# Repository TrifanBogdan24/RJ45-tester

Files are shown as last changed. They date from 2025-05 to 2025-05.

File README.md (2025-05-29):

# RJ45 Tester

## Introducere

### De la idee la prototip

Vă amintiți primul laborator de **RL**?

Acolo am învățat cum să realizăm un **cablu UTP** pentru rețele Ethernet,
Procesul poarta numele de **sertizare**.
După realizarea cablului, acesta trebuie verificat ca functioneaza corect - adică dacă are continuitate.

Testarea se face folosind un dispozitiv dedicat.

De aici a pornit ideea proiectului meu: realizarea propriului meu [tester RJ45](https://www.optimusdigital.ro/ro/aparate-de-masura/4962-tester-rj45-rj11.html?search_query=rj45&results=22),
caruia i-am adus o serie de îmbunătățiri.

### Ce face dispozitivul?

Dispozitivul proiectat permite testarea cablurilor de rețea de tip **RJ45**,
oferind feedback vizual și auditiv privind corectitudinea conexiunilor dintre pini.

Prin simpla apăsare a unui buton, utilizatorul poate selecta tipul de cablu testat:
1. **Straight-through** - pentru conectarea dispozitivelor aflate pe *layere diferite* (ex: PC – switch)
2. **Crossover** - pentru conectarea dispozitivelor de *același layer* (ex: PC - PC)
3. **Rollover** (numit si *cablu de consola*) - pentru a conecta un dispozitiv la un echipament de retea si pentru a avea acces direct la CLI

După selectare, pe ecranul principal (128x160 SPI) este afișată o imagine cu ordinea corectă a firelor pentru tipul respectiv de cablu.

Rolul hardware-ului in testare:
- Se folosesc 2 socketi: unul dedicat pentru **sender**, iar celalalt pentru **receiver**
-  Fiecare soclu RJ-45 are 8 pini
- Fiecarui pin RJ-45 ii este asociat un LED de culoare verde care se va aprinde
    atunci cand semnalul transmis/primit pe pinul respectiv este de 1 logic.
- In momentul in care socket-ul de **receiver** receptioneaza **1 logic**, buzzer-ul va emite un beep scurt

Testarea efectiva presupune 2 verificari:
1. Se vor trimite semnale, secvential, iterand pinii **sender**-ului unul cate unul, cu mici pauze intre transmisii,
2. urmand un test final in care se vor activa simultan toti pinii **sender**-ului

Testar-ul poate fi oprită forțat, in orice moment,  prin apăsarea unui buton.

In timp ce display-ul pe SPI (de rezolutie mai mare)
afiseaza ordinea firelor in mufa RJ-45,
LCD-ul cu modul I2C va scrie pe ecran tipul de cablu **straight-through**/**crossover**
si indexul pinului de pe **sender** de pe care se trimit semnale
(e.g. *"Testing pin 1...8"*), sau mesajul *"Testing all pins"*.

### De ce este util?

Consider ca folosirea ecranelor face diferenta dintre un tester RJ-45 obisnuit
si device-ul.

Practic, este un instrument **"2 în 1"**: tester + ghid de conectare.

Sper ca dispozivitul pe care il proiectez
(imi propun sa ii fac si un **PCB compact**)
sa ajunga in mainile laborantilor de RL/CCNA1.
Acolo isi va atinge adevaratul potential.

## Descriere Generala

Schema bloc:

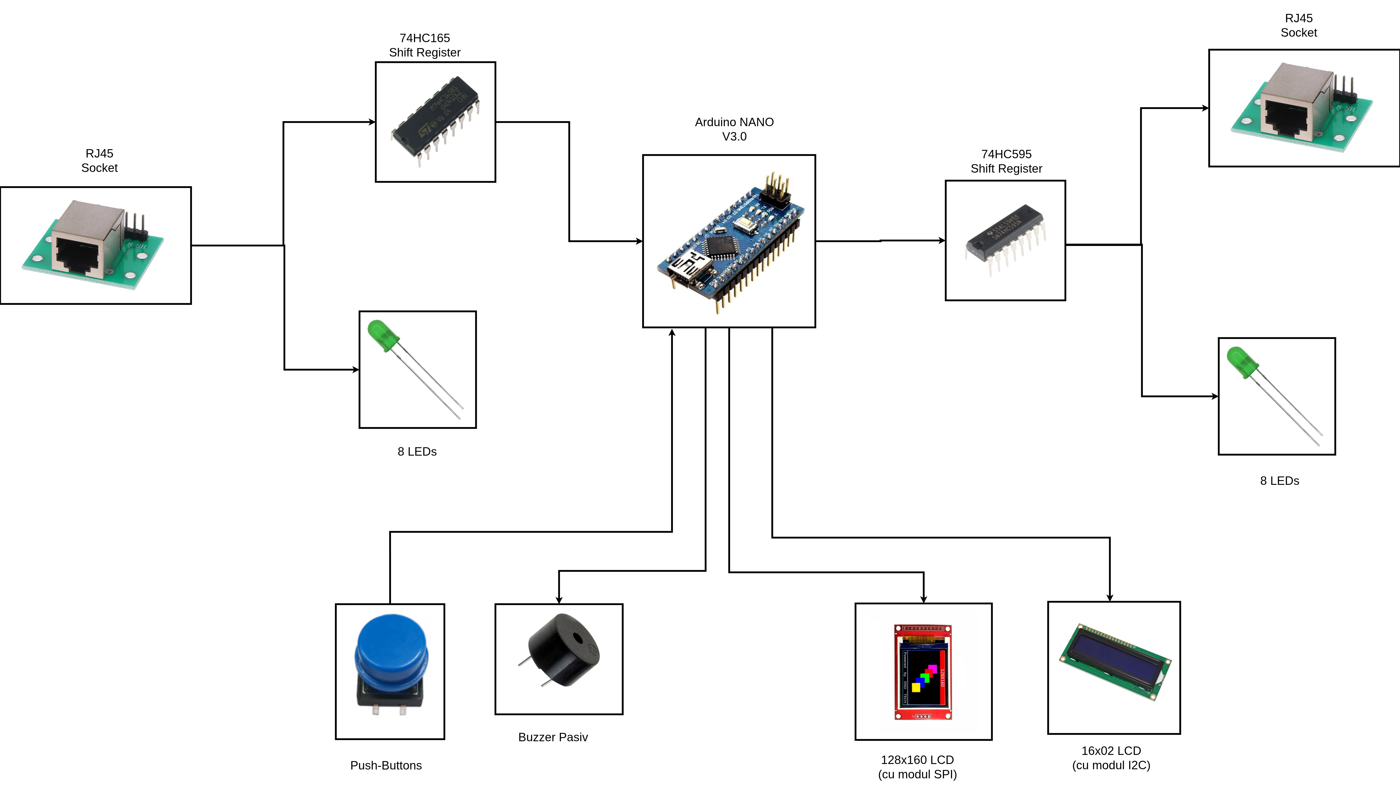
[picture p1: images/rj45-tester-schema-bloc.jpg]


## Hardware Design

### Lista Componente

| Componenta | Pret |
| :--- | :--- |
| [Arduino Nano V3.0](https://www.emag.ro/placa-de-dezvoltare-nano-v3-0-atmega328p-ch340-cu-cablu-usb-1414dr/pd/DTDC88YBM/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) | ~40 lei |
| 2x [RJ45 Adapter Board + Breakout Board + Pin Header](https://www.aliexpress.com/item/1005006421216570.html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) (de pe AliExpress 😊) | ~8 lei fiecare |
| 1x [74HC595 8-bit Shift Register](https://ardushop.ro/ro/circuite-integrate/1657-ic-shift-register-sn74hc595n-74hc595-6427854024978.html) (1 pin intrare, 8 pini de iesire) | 4 lei |
| 1x [74HC165 8-bit Shift Register](https://ardushop.ro/ro/electronica/683-74hc165-8-bit-shift-register-6427854008602.html) (1 pin iesire, 8 pini de intrare) | 8 lei |
| [LCD 16x02 cu interfata I2C](https://www.optimusdigital.ro/ro/optoelectronice-lcd-uri/2894-lcd-cu-interfata-i2c-si-backlight-albastru.html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) | ~16 lei |
| [Modul LCD SPI 160x128](https://ardushop.ro/ro/electronica/2124-modul-lcd-spi-128x160-6427854032546.html) | ~44 lei |
| 16x [LED Verde 3mm cu Lentile Difuze](https://www.optimusdigital.ro/ro/optoelectronice-led-uri/697-led-verde-de-3-mm-cu-lentile-difuze.html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) | 0,40 lei fiecare |
| 16x Rezistente 220 Ω (pt LED-uri) | |
| [Buzzer Pasiv](https://www.optimusdigital.ro/ro/audio-buzzere/12247-buzzer-pasiv-de-33v-sau-3v.html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) | 1 leu |
| 3x [Buton cu Capac Rotund](https://www.optimusdigital.ro/ro/butoane-i-comutatoare/1115-buton-cu-capac-rotund-alb.html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) | 2 lei fiecare |
| 3x Rezistente (de PULL-UP) de 10 kΩ (pt butoane) |
| 3x [Condensatoare ceramice de 47nF](https://www.optimusdigital.ro/ro/componente-electronice-condensatoare/7817-condensator-ceramic-47-nf-50-v.html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) (pt butoane) | 0,50 lei fiecare |
| 3x [Breadboard 830 puncte](https://ardushop.ro/ro/electronica/2297-breadboard-830-puncte-mb-102-6427854012265.html) | 20 lei fiecare |
| [Set fire Plusivo cu izolatie PVC (Fir unifilar) - 22 AWG](https://www.optimusdigital.ro/ro/kituri/12264-set-de-fire-cu-izolaie-pvc-22awg-6-culori-10m-fiecare-0721248989765.html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) | 45 lei |
| Jumpere tata-tata | |
| Jumpere mama-tata | |

> Set fire PVC:
>   - Size matters: cele de **22 AWG** se conecteaza cel mai bine in breadboard
>   - Calalalt tip de fire (silicon - multifilar): sunt bune de lipit, dar in niciun caz nu se pot infige intr-un breadboard

**Componente auxiliare**, specifice tester-ului RJ-45:
| Componenta | Pret |
| :--- | :--- |
| 2 metri cablue UTP | 0 lei (de la CCNA 😊)  |
| [Cleste Universal Sertizat Conectori RJ-45](https://www.emag.ro/cleste-universal-sertizat-conectori-rj-45-rj-12-rj-11-lhpnar0051/pd/DB3JFDBBM/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) | 15 lei |
| [SET 50 Buc - Mufa RJ45 UTP/FTP cu 8 pini 8P8C](https://www.emag.ro/set-50-buc-mufa-rj45-utp-ftp-cu-8-pini-8p8c-s50-rj45/pd/DZ94TCBBM/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) | 15 lei |
| [Tester Continuitate RJ45](https://www.optimusdigital.ro/ro/aparate-de-masura/4962-tester-rj45-rj11.html?search_query=rj45&results=22) | 15 lei |
| Baterie 9V | |

### Schema Electrica

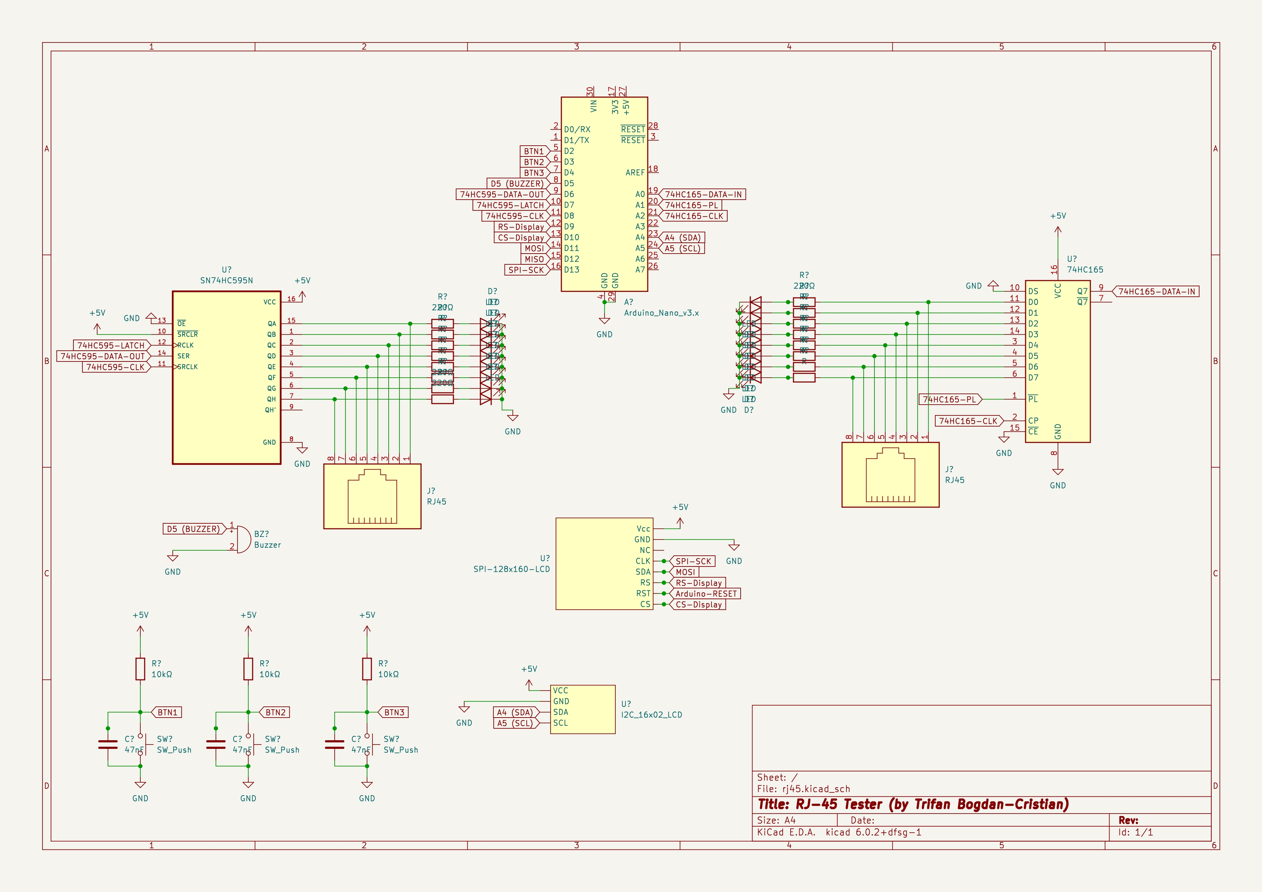
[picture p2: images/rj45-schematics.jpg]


### Pin configurations

#### Arduino

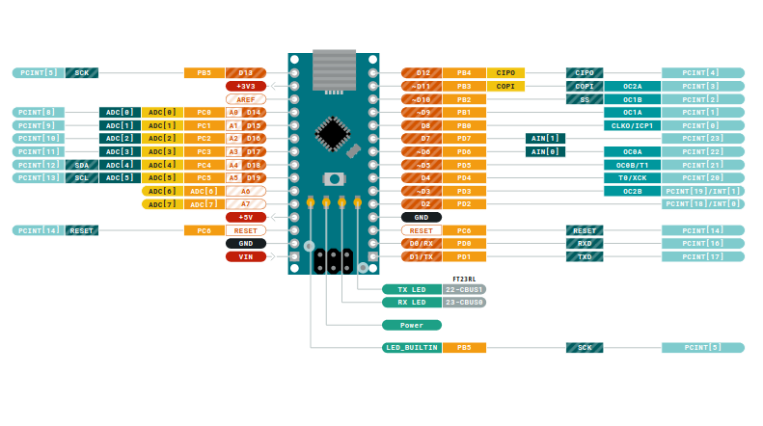
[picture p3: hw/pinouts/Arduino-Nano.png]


| Pin Arduino | Corespondent |
| :--- | :--- |
| D2 | Butonul albastru (BTN1) |
| D3 | Butonul rosu (BTN2) |
| D4 | Butonul alb (BTN3) |
| D5 | Buzzer pasiv |
| D6 | Data OUT 74HC595 (SER) |
| D7 | Latch 74HC595 (RCLK) |
| D8 | Clock 74HC595 (SRCLK) |
| D9 | RS-Display |
| D10 | CS-Diplsay |
| D11 | (SPI) MOSI |
| D12 | (SPI) MISO |
| D13 | (SPI) SCK|
| D14 (etichetat A0) | Data IN 74HC165 |
| D15 (etichetat A1) | PL 74HC165 |
| D16 (etichetat A2) | CLK 74HC165 |
| A4 | (I2C) SDA |
| A5 | (I2C) SCL |

#### 160x128 Display (pe SPI)

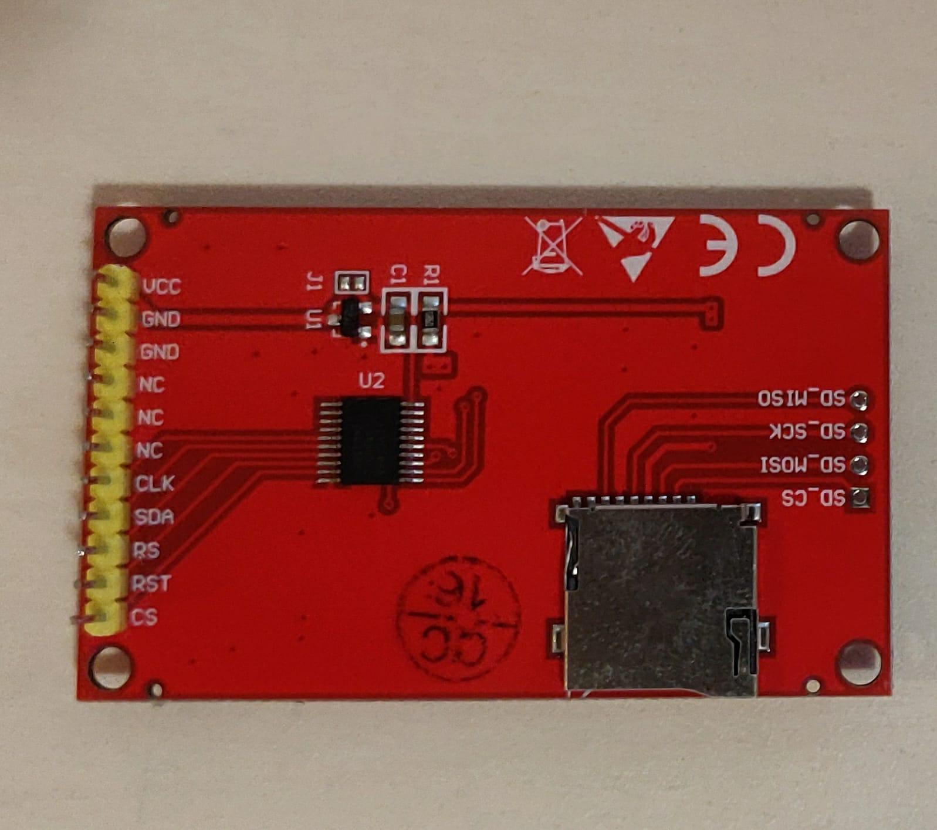
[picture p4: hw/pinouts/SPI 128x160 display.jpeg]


| Denumire pin | Descriere |
| :--- | :--- |
| Vcc | Vcc
| GND | Ground |
| NC | Not Connected (nu se conecteaza la nimic) |
| CLK | Clock |
| SDA | este pinul de **MOSI** (foarte confuz ca au scris SDA in loc de **MOSI**) |
| RS | Register Select |
| RST | Reset |
| CS | Chip Select |

> Pinul RS (Register Select) este cunoscut si sub numele de DC (Data Command).
> 
> Acest pin indica daca datele trimise pe SPI sunt:
> - comenzi (e.g.: seteaza pozitia cursorului)
> - date (e.g. afiseaza pixeli pe ecran)
> 
> Pinul are urmaoare functionalitate:
> - Daca RS/DC = 0 -> comanda
> - Daca RS/DC = 1 -> date

| Pin Display SPI | Corespondent |
| :--- | :--- |
| Vcc | 5V |
| GND | GND |
| NC | nu se conecteaza la nimic |
| CLK | Arduino D13 (SPI SCK) |
| SDA | Arduino D11 (SPI MOSI) |
| RS | Arduino D9 |
| RST | Arduino RESET |
| CS | Arduino D10 |

#### 74HC595 shift register

> Shift register-ul **74HC595** are o singura intrare si **8 iesiri paralele**.

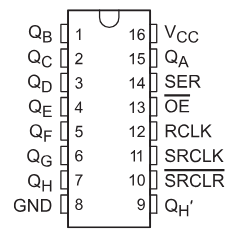
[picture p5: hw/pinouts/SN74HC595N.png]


| Index pin 74HC595 | Denumire pin 74HC595 | Corespondent |
| :--- | :--- | :--- |
| 15 | Q<sub>A</sub> | LED 1 (cel mai de sus) & pin 1 socket RJ-45 sender |
| 1  | Q<sub>B</sub> | LED 2 (al doilea cel mai de sus) & pin 2 socket RJ-45 sender |
| 2  | Q<sub>C</sub> | LED 3 & pin 3 socket RJ-45 sender |
| 3  | Q<sub>D</sub> | LED 4 & pin 4 socket RJ-45 sender |
| 4  | Q<sub>E</sub> | LED 5 & pin 5 socket RJ-45 sender |
| 5  | Q<sub>F</sub> | LED 6 & pin 6 socket RJ-45 sender |
| 6  | Q<sub>G</sub> | LED 7 & pin 7 socket RJ-45 sender |
| 7  | Q<sub>H</sub> | LED 8 & pin 8 socket RJ-45 sender |
| 8  | GND | GND |
| 9  | !Q<sub>H</sub> | nmk |
| 10 | !SRCLR | 5V |
| 11 | SRCLK | Arduino D8 |
| 12 | RCLK | Arduino D7 |
| 13 | !OE | GND |
| 14 | SER | Arduino D6 |
| 16 | Vcc | 5V |

> LED-ul la care fac referire aici sunt cele din **partea stanga**, asociate **sender**-ului.

#### 74HC165 shift register

> Shift register-ul **74HC165** are o singura iesire si **8 intrari paralele**.

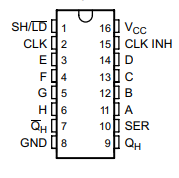
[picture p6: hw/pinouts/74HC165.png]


| Index pin 74HC165 | Denumire pin 74HC165 | Corespondent |
| :--- | :--- | :--- |
| 7 | !Q<sub>H</sub> | nmk |
| 9 | Q<sub>H</sub> | Arduino D14 (etichetat A0) |
| 1 | SH/!LD | Arduino D15 (etichetat A1) |
| 2 | CLK | Arduino D16 (etichetat A2) |
| 8 | GND | GND |
| 16 | Vcc | 5V |
| 10 | SER | GND |
| 15 | CLK INH | GND |
| 11 | A (out1) | LED 1 (cel mai de sus) & pin 1 socket RJ-45 receiver |
| 12 | B (out1) | LED 2 (al doilea cel mai de sus) & pin 2 socket RJ-45 receiver |
| 13 | C (out1) | LED 3 & pin 2 socket RJ-45 receiver |
| 14 | D (out1) | LED 4 & pin 3 socket RJ-45 receiver |
| 3 | E (out1) | LED 5 & pin 4 socket RJ-45 receiver |
| 4 | F (out1) | LED 6 & pin 5 socket RJ-45 receiver |
| 5 | G (out1) | LED 7 & pin 6 socket RJ-45 receiver |
| 6 | H (out1) | LED 8 & pin 7 socket RJ-45 receiver |

> LED-ul la care fac referire aici sunt cele din **partea dreapta**, asociate **receiver**-ului.

### Debounce butoane: Filtru trece-jos

Pentru a trata **debounce-ul butoanelor** exclusiv din hardware,
m-am gandit sa introduc in circuit un **filtru trece-jos**,
punand cate un condensator ceramic in paralel cu fiecare buton.

Constanta de timp τ:

```
τ = R*C =10kΩ*47nF = 10^4 + 47*10^(-9) = 47*10^(-5) = 470us

5*τ=5*470μs≈2.35ms
```

Astfel, schimbarile mai rapide de **2.35 ms** ale butoanelor
vor fi ignorate (la nivel hardware) de aceste filtre.

> Chiar si asa, eu tot am lasat in cod un mic **delay**
> (unul mult mai mare decat ce poate circuitul construit de mine sa filtreze).

### Progresul fizic, pe etape

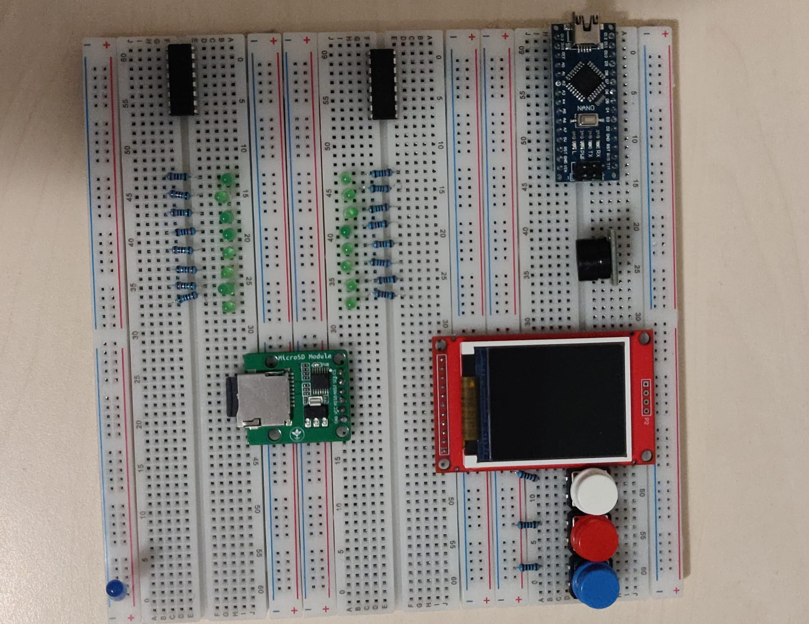
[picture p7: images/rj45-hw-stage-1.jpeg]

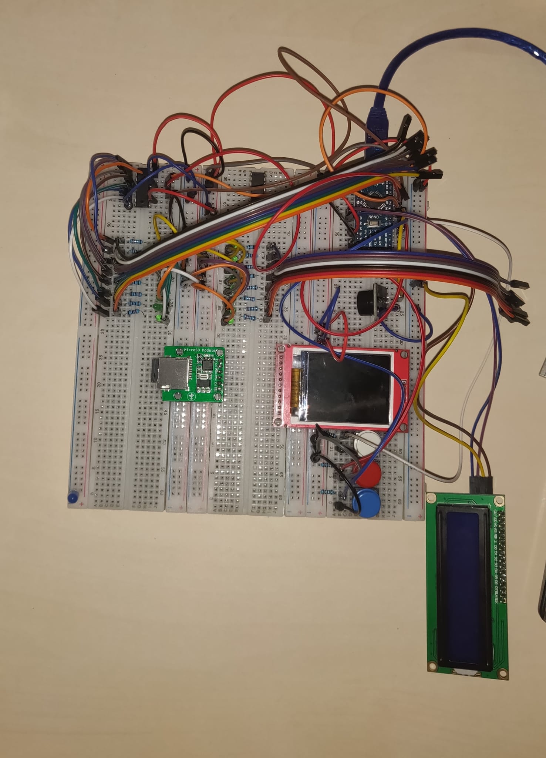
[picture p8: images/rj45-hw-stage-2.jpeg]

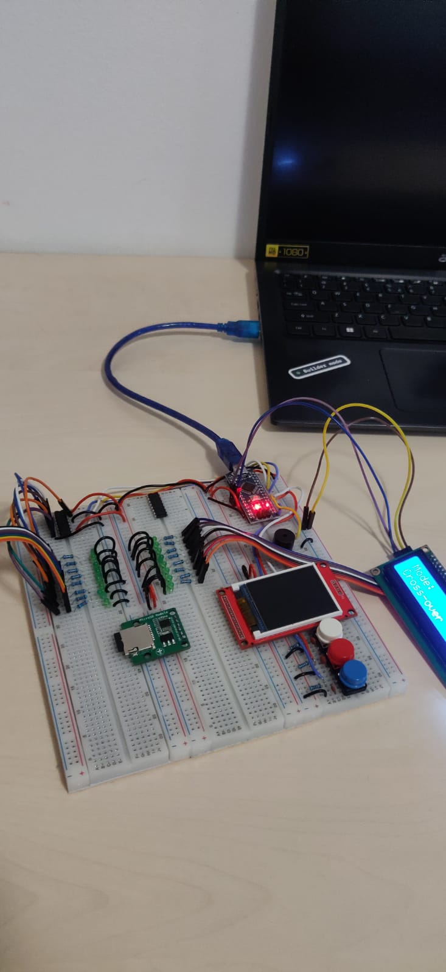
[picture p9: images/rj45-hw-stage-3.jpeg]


## Software Design

Biblioteci folosite:
- **Arduino.h**: biblioteca default pentru placa de dezvoltare
- **LiquidCrystal_I2C.h**: imi permite scrierea caracterelor pe ecranul secundar (cel pe I2C, de rezolutie 16x02)
- **Adafruit_GFX.h**, **Adafruit_ST7735.h**: pentru interactiunea cu display-ul principal (cel pe SPI, de rezolutie 160x128)

Repo GitHub: <https://github.com/TrifanBogdan24/RJ45-tester> - codul sursa se gaseste in folderul **src/**.

Am asociat fiecarui buton cate o intrerupere:
- Butonul **albastru** - intreruperea **INT0** - schimba tipul de cablare (crossover/straigh-through)
- Butonul **rosu** - intreruperea **INT1** - opreste fortat rularea testului
- Butonul **alb** - intreruperea **PCINT20** (din **PCINT2_vect**)  - porneste algoritmul de testare:

Descrierile functiilor:
- `ISR(INT0_vect)`:
  - rutina de tratare a intreruperii, generata la apasarea butonului **albastru** (schimba tipul de cablare)
  - Marcheaza flag-ul `volatile bool pressedBTN1`
- `ISR(INT1_vect)`: 
  - rutina de tratare a intreruperii, generata la apasarea butonului **rosu** (oprirea fortata a algoritmului de testare)
  - Marcheaza flag-ul `volatile bool pressedBTN2`
- `ISR(PCINT2_vect)`:
  - rutina de tratare a intreruperii, generata la apasarea butonului **alb** (pornirea algoritmului de testare)
  - Marcheaza flag-ul `volatile bool pressedBTN3`
- `void beep_okay()`: controleaza buzzer-ul sa emita bazait scurt, in semn ca totul este in regula
- `void beep_not_okay()`: controleaza buzzer-ul sa emita un semnal sonor de eroare
- `void cable_type_first_line_lcd()`: scrie tipul de cablare pe prima linia a LCD-ului de rezolutie 16x02
- `void cable_mode_full_lcd()`:
  scrie pe textul "Mode:" pe prima linia a display-ului secundar (cel pe I2C, de 16x02),
  iar pe a doua, tipul de cablare
- `void force_stop_handler()`:
  - Functia este apelata in urma apasarii butonului **rosu**.
  Opreste fortat algoritmul de testare,
  dar nu inainte de a afisa pe ecranul LCD pe I2C un mesaj sugestiv in acest sens
  `lcd.print("Force stop!");`
- `void write_to_sender_socket()`:
  - Variabila `bool pinsSenderSocket[8]` retine starea pinilor din mufa RJ-45 de transmisie
  - Functia scrie valorile din `bool pinsSenderSocket[8]` in shift register-ul **74HC595**,
  - Scrierea (chiar si pe un singur pin) al socket-ului sender presupune scrierea tuturor celor 8 valori
    catre **shift register**, in ordine inversa
    (intrucat acesta foloseste **MSB**: prima valoare primita va fi asociata ultimului pin)
- `void init_sender_pins()`:
  Este apelata la pornirea micro-controler-ului
  pentru a trata starea initiala indefinita
  (uneori LED-uri se pot aprinde aleator, fara ca eu nici macar sa fi scris ceva in shift register)
  a shift register-ului **74HC595**, asociat socket-ului sender.
- `void fetch_receiver_socket()`:
  Citeste valorile de pe shift register-ul **74HC165** (asociat socket-ului receiver)
  si le scrie in variabila `bool pinsReceiverSocket[8];`
- `bool is_correct_wiring(int pin_index)`:
  - Apeleaza `is_correct_wiring` pentru a citi semnalele de pinii socket-ului receiver
  - Si verifica daca valorile corespund unei cablari corecte,
  in raport cu indexul pinului activat pe mufa RJ-45 de transmisie
- `int test_individual_rj45_pins()`:
  - Algoritmul propriu zis de testare
  - Parcurge iterativ, de la 1 la 8, toti pinii socket-ului sender si
    1. Scrie pe ecranul secundar (16x02): modul de cablare, indexul pinului RJ-45 de transmisie
      si indexul corect pe care se asteapta sa primeasca semnal de pe pinul RJ-45 de receptie
    2. Scrie "1 logic" in iesirea (shift register-ului) **74HC595** corespunzatoare pinului ales:
      lucru care va produce aprinderea unui LED
    3. Ruleaza un mic `delay()` pentru a ma asigura ca semnalul are timp sa ajunga de la un capat la altul
    4. Apeleaza functia `is_correct_wiring` pentru a afla daca semnalul ajuns unde trebuie:
      - Daca da, va scrie in *"OK"* in coltul dreapta-jos al display-ului secundar si va emita un bapait scurt
      - Altfe, va scrie *"NOK"* pe LCD si va produce un sunet de avertistment
  - Functia verifica constant daca butonul **rosu** a fost apasat (flag-ul `pressedBTN2` a fost setat),
    caz in care opreste fortat algorimul de testare, apeland `force_stop_handler()` in cod
- `void init_tft_lcd()`: initializeaza display-ul principal (cel pe SPI, de rezolutie 160x128)
- `void draw_straight_through_wiring()`/`void draw_crossover_wiring()`/`void draw_rollover_wiring()`:
  - Aceste functii afiseaza grafic ordinea firelor pentru cele doua capete ale unui cablu de retea
  - In functie de tipul de cablare selectat (straight-through/crossover/rollover)
  - Ordinea firelor este redata conform standardelor prezentate in **cursul de RL**
- `setup()`
  - configureza pinii de Input/Outpt
  - activeaza intreruperile
  - initiaza display-urile
  - scrie in registrii
- `loop()`
  - Verifica si trateaza flag-urile `pressedBTN1` si `pressedBTN3`
  - > NOTA: flag-ul `pressedBTN2` este tratat in interiorul algoritmului de testare (in functia `test_individual_rj45_pins()`)
  - Reseteaza flag-urile
  - Ruleaza `delay()`

```c
tft.fillRect(x_upper_left_corner, y_upper_left_corner, width, height, ST77XX_<color>);
```

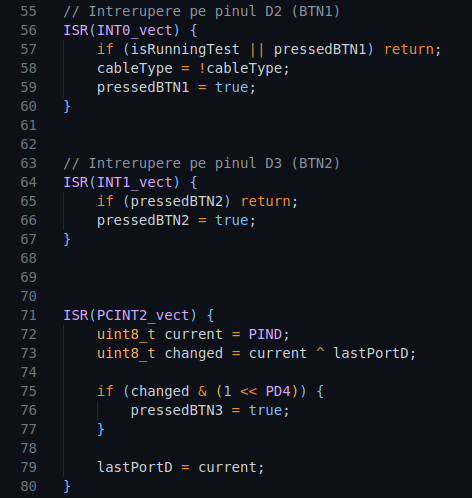
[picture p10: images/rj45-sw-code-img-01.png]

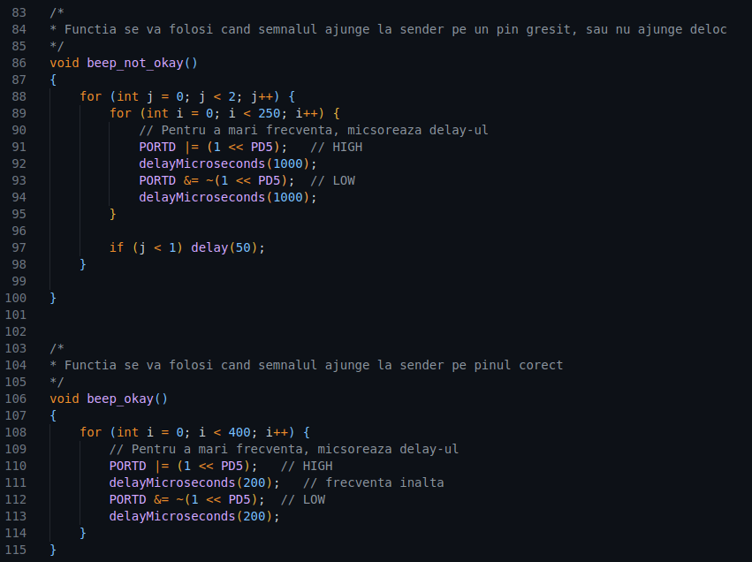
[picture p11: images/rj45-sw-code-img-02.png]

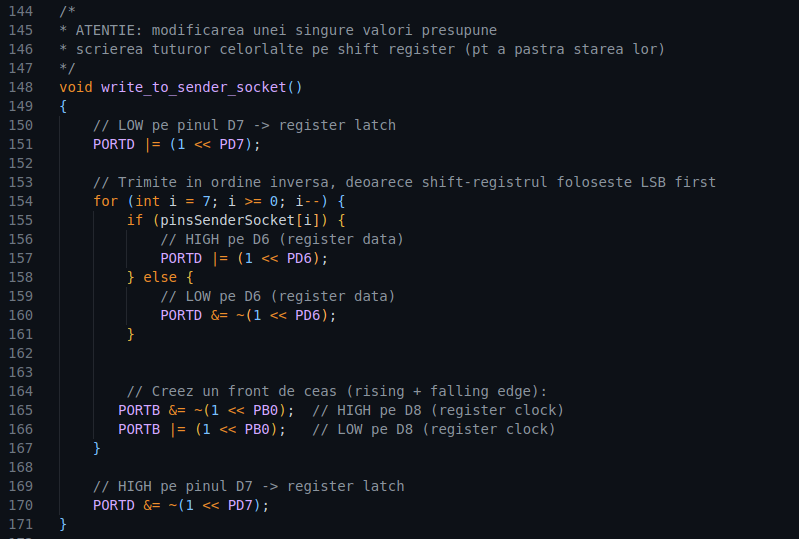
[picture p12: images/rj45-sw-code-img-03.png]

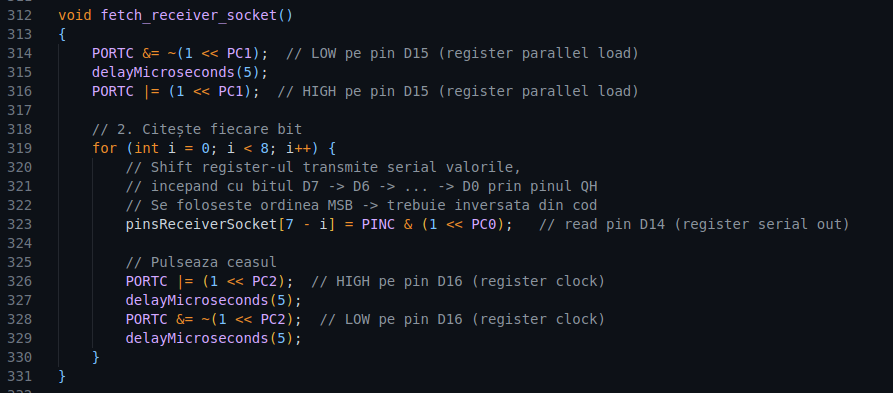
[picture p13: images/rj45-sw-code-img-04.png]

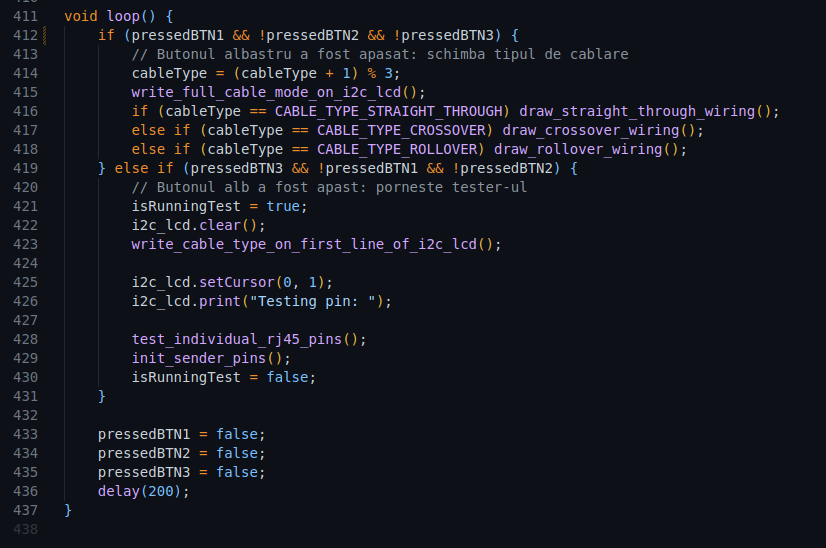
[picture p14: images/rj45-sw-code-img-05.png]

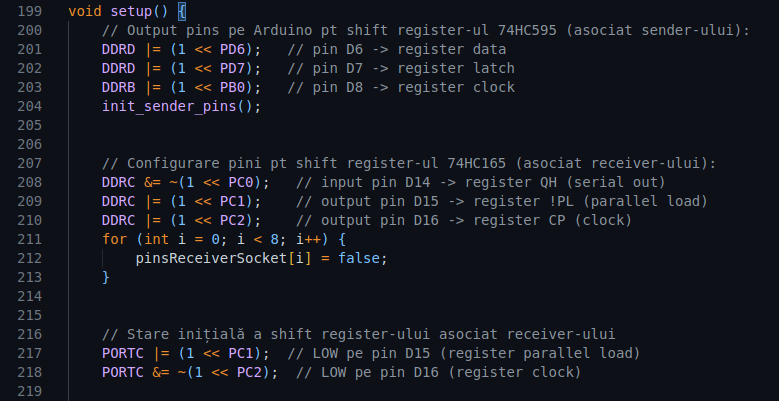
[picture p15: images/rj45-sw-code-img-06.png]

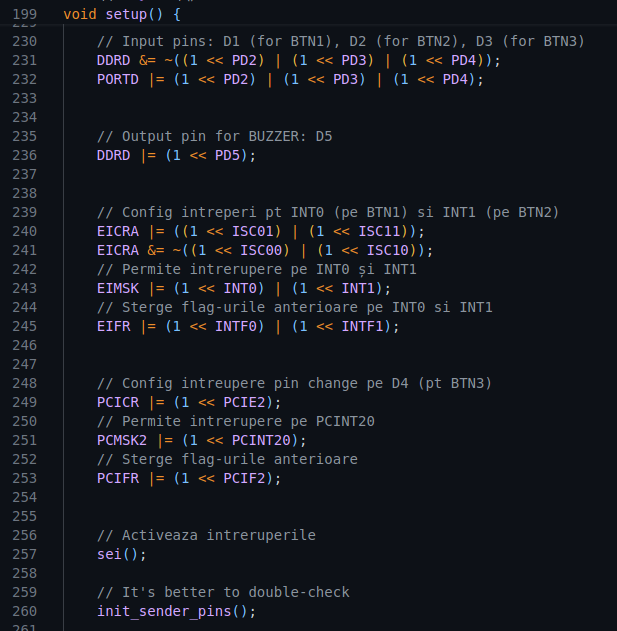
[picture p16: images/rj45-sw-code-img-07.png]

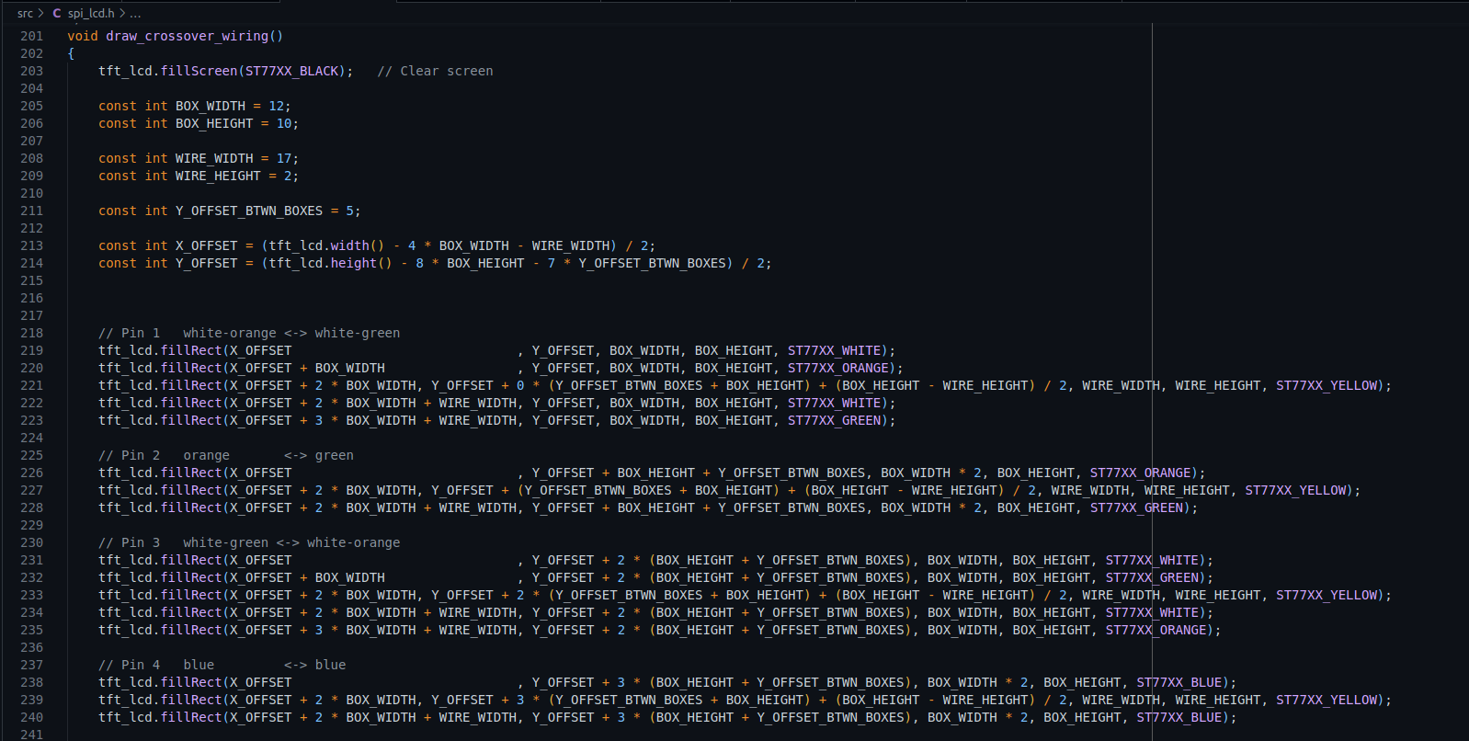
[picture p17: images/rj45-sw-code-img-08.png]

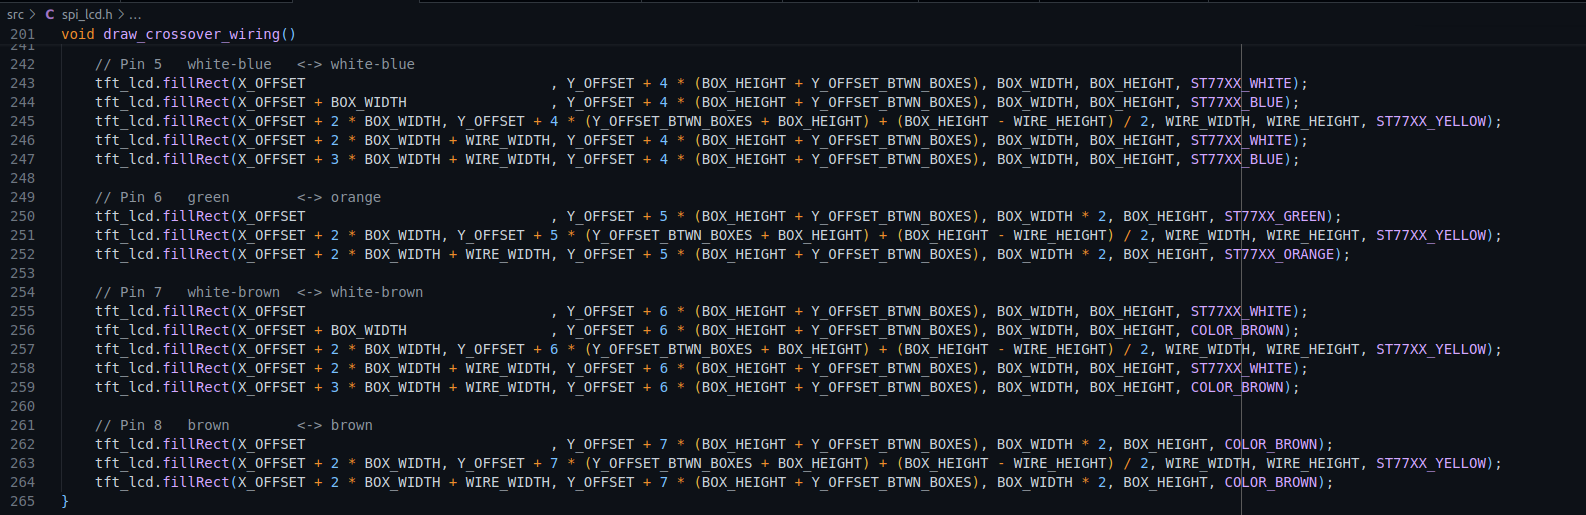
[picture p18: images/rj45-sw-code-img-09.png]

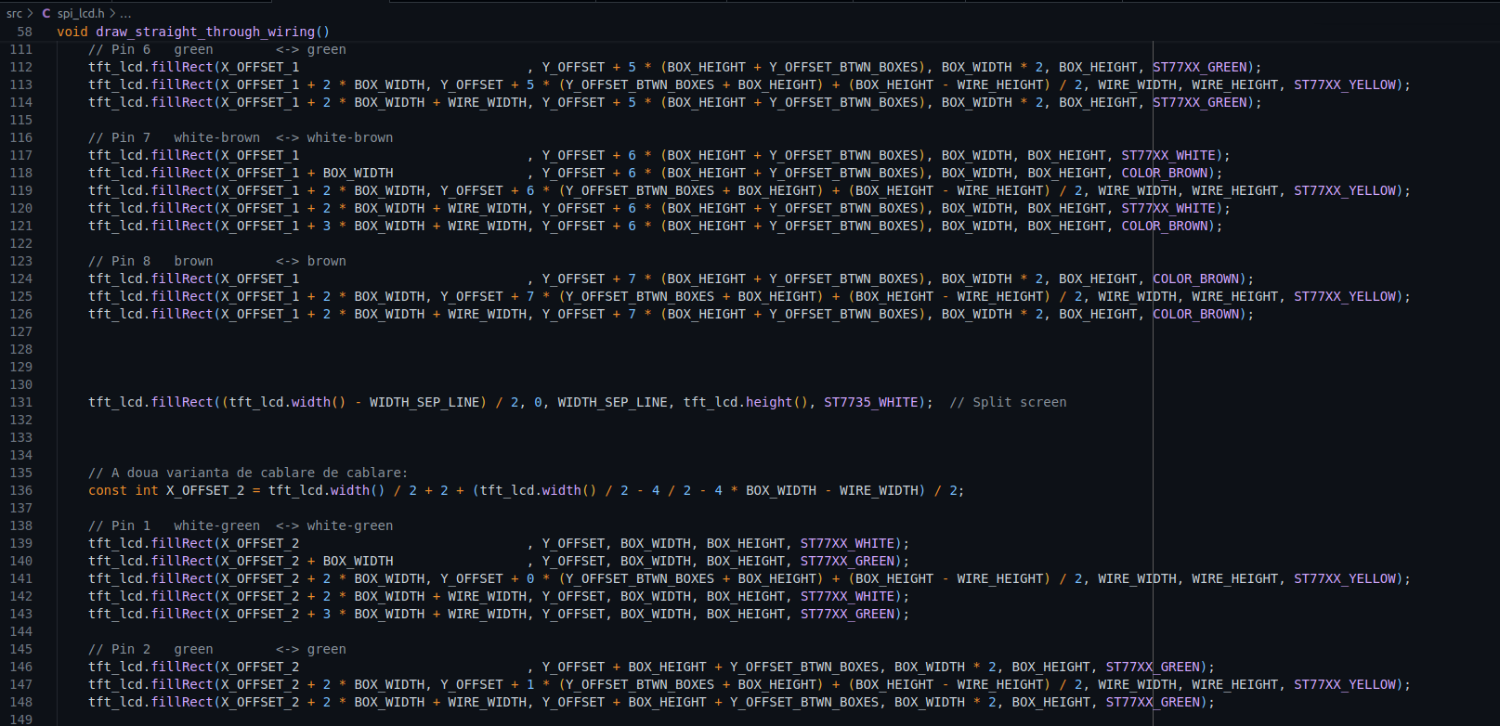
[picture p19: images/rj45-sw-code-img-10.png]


Repo GitHub: <https://github.com/TrifanBogdan24/RJ45-tester>

YouTube: <https://www.youtube.com/shorts/1yIg8dGbAU8>

## Concluzii

- Dat fiind faptul ca nu am avut succes la afisarea pe ecranul 160x128 a unor imagini **.bmp** luate de pe un card microSD,
  a trebuit sa renunt complet la modulul microSD
- In alta ordine de idei, pentru a desena modul de cablare, am mers pe o idee mai programatica,
  **EGC**-style: m-am apucat si am desenat eu dreptunghiuri pe ecran, colorandu-ule corespunzator.
  Rezultatul final cred ca este mult mai bun decat daca as fi transformat niste screen-shoot-uri la imagini **.bmp** de rezolutie joasa
- Cateva probleme pe care le-am intampinat in timpul acestui proiect au fost create de **shift register**-ul **74HC595** (cel cu 8 iesiri paralele):
  - Are o stare initiala random (am rezolvat scriind 0 logic pe toate iesirile)
  - Exista un **delay** (am observat ca este undeva la **200-300 ms**) din momentul in care dau o valoare inspre shift register si momentul in care semnalul iese corect din acesta 

## Resurse folosite

Pt cablurile pe care le folosesc pe breadboard: <https://www.youtube.com/shorts/3qbz26m9SPA>

[#13 How To Create Custom Symbols in KiCad 7.0 With KLC](https://www.youtube.com/watch?v=baCGoK8MuH0)

Data-sheets:
- [Arduino NANO pinout](https://docs.arduino.cc/resources/pinouts/A000005-full-pinout.pdf)

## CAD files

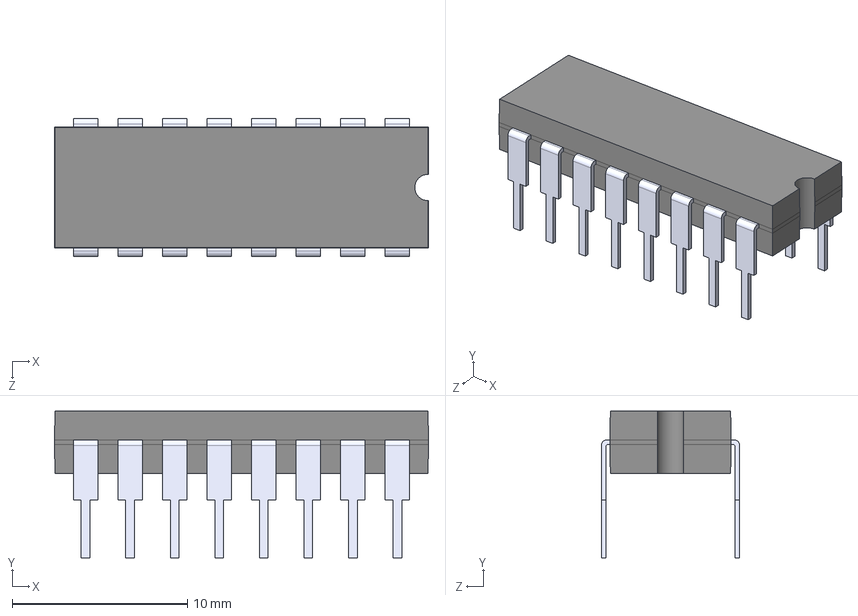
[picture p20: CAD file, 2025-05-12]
hw/rj45-kicad/SN74HC595N/SN74HC595N.step
21.3 x 8.38 x 7.90 mm

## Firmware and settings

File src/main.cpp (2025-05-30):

#include <Arduino.h>
#include <LiquidCrystal_I2C.h>
#include "spi_lcd.h"


#define CABLE_TYPE_STRAIGHT_THROUGH (int) 0
#define CABLE_TYPE_CROSSOVER        (int) 1
#define CABLE_TYPE_ROLLOVER         (int) 2



// Pini rezervati pe Arduino pt display-ul pe SPI (128x160):
#define PIN_IMAGE_DIPSLAY_CS (int) 10  // Chip Select -> D10
#define PIN_IMAGE_DISPLAY_RS (int) 14  // Register Select -> A0 (D14)




LiquidCrystal_I2C i2c_lcd(0x27, 16, 2);


// 0 = Straight-through ; 1 = Crossover ; 2 = Rollover
int cableType = CABLE_TYPE_STRAIGHT_THROUGH;
int imageTypeOnDisplay = 0;

volatile bool pressedBTN1 = false;   // Blue button (switch cable type)
volatile bool pressedBTN2 = false;   // Red button (force stop)
volatile bool pressedBTN3 = false;   // White button (start tester)

bool isRunningTest = false;

// Pentru intreruperile pe PCINT
volatile uint8_t lastPortD = 0;


const int dataPin = A1;  // QH (serial out)
const int plPin   = A2;  // /PL (parallel load)
const int clkPin  = A3;  // CP (clock)

// Vector de stocare a bitilor
bool pinsReceiverSocket[8];
bool pinsSenderSocket[8];



// Intrerupere pe pinul D2 (BTN1)
ISR(INT0_vect) {
    if (isRunningTest) return;
    pressedBTN1 = true;
}


// Intrerupere pe pinul D3 (BTN2)
ISR(INT1_vect) {
    pressedBTN2 = true;
}



ISR(PCINT2_vect) {
    if (isRunningTest) return;

    uint8_t current = PIND;
    uint8_t changed = current ^ lastPortD;

    if (changed & (1 << PD4)) {
        pressedBTN3 = true;
    }

    lastPortD = current;
}


/*
* Functia se va folosi cand semnalul ajunge la sender pe un pin gresit, sau nu ajunge deloc
*/
void beep_not_okay()
{
    for (int j = 0; j < 2; j++) {
        for (int i = 0; i < 250; i++) {
            // Pentru a mari frecventa, micsoreaza delay-ul
            PORTD |= (1 << PD5);   // HIGH
            delayMicroseconds(1000);
            PORTD &= ~(1 << PD5);  // LOW
            delayMicroseconds(1000);
        }

        if (j < 1) delay(50);
    }

}


/*
* Functia se va folosi cand semnalul ajunge la sender pe pinul corect
*/
void beep_okay()
{
    for (int i = 0; i < 400; i++) {
        // Pentru a mari frecventa, micsoreaza delay-ul
        PORTD |= (1 << PD5);   // HIGH
        delayMicroseconds(200);   // frecventa inalta
        PORTD &= ~(1 << PD5);  // LOW
        delayMicroseconds(200);
    }
}

void write_cable_type_on_first_line_of_i2c_lcd()
{
    i2c_lcd.setCursor(0, 0);
    if (cableType == CABLE_TYPE_STRAIGHT_THROUGH) {
        i2c_lcd.print("Straight-through");
    } else if (cableType == CABLE_TYPE_CROSSOVER) {
        i2c_lcd.print("Crossover      ");
    } else if (cableType == CABLE_TYPE_ROLLOVER) {
        i2c_lcd.print("Rollover        ");
    }
}


void write_full_cable_mode_on_i2c_lcd()
{
    i2c_lcd.clear();
    i2c_lcd.setCursor(0, 0);
    i2c_lcd.print("Mode:");
    i2c_lcd.setCursor(0, 1);

    if (cableType == CABLE_TYPE_STRAIGHT_THROUGH) {
        i2c_lcd.print("Straight-through");
    } else if (cableType == CABLE_TYPE_CROSSOVER) {
        i2c_lcd.print("Crossover      ");
    } else if (cableType == CABLE_TYPE_ROLLOVER) {
        i2c_lcd.print("Rollover        ");
    }
}



/*
* ATENTIE: modificarea unei singure valori presupune
* scrierea tuturor celorlalte pe shift register (pt a pastra starea lor)
*/
void write_to_sender_socket()
{
    // HIGH pe pinul D7 -> register latch
    PORTD |= (1 << PD7);
  
    // Trimite in ordine inversa, deoarece shift-registrul foloseste LSB first
    for (int i = 7; i >= 0; i--) {
        if (pinsSenderSocket[i]) {
            // HIGH pe D6 (register data)
            PORTD |= (1 << PD6);
        } else {
            // LOW pe D6 (register data)
            PORTD &= ~(1 << PD6);
        }
  

        // Creez un front de ceas (rising + falling edge):
       PORTB &= ~(1 << PB0);  // LOW pe D8 (register clock)
       PORTB |= (1 << PB0);   // HIGH pe D8 (register clock)
    }
  
    // LOW pe pinul D7 -> register latch
    PORTD &= ~(1 << PD7);
}


void init_sender_pins()
{
    for (int i = 0; i < 8; i++) {
        pinsSenderSocket[i] = false;
    }
    write_to_sender_socket();
}





void setup() {
    // Output pins pe Arduino pt shift register-ul 74HC595 (asociat sender-ului):
    DDRD |= (1 << PD6);   // pin D6 -> register data
    DDRD |= (1 << PD7);   // pin D7 -> register latch
    DDRB |= (1 << PB0);   // pin D8 -> register clock
    init_sender_pins();


    // Configurare pini pt shift register-ul 74HC165 (asociat receiver-ului):
    DDRC &= ~(1 << PC0);   // input pin D14 -> register QH (serial out)
    DDRC |= (1 << PC1);    // output pin D15 -> register !PL (parallel load)
    DDRC |= (1 << PC2);    // output pin D16 -> register CP (clock) 
    for (int i = 0; i < 8; i++) {
        pinsReceiverSocket[i] = false;
    }


    // Stare inițială a shift register-ului asociat receiver-ului
    PORTC |= (1 << PC1);  // LOW pe pin D15 (register parallel load)
    PORTC &= ~(1 << PC2);  // LOW pe pin D16 (register clock)


    cableType = CABLE_TYPE_STRAIGHT_THROUGH;
    imageTypeOnDisplay = 0;

    i2c_lcd.begin(16, 2);
    i2c_lcd.backlight();

    write_full_cable_mode_on_i2c_lcd();


    // Input pins: D1 (for BTN1), D2 (for BTN2), D3 (for BTN3)
    DDRD &= ~((1 << PD2) | (1 << PD3) | (1 << PD4));
    PORTD |= (1 << PD2) | (1 << PD3) | (1 << PD4); 


    // Output pin for BUZZER: D5
    DDRD |= (1 << PD5);


    // Config intreperi pt INT0 (pe BTN1) si INT1 (pe BTN2)
    EICRA |= ((1 << ISC01) | (1 << ISC11));
    EICRA &= ~((1 << ISC00) | (1 << ISC10));
    // Permite intrerupere pe INT0 și INT1
    EIMSK |= (1 << INT0) | (1 << INT1);
    // Sterge flag-urile anterioare pe INT0 si INT1
    EIFR |= (1 << INTF0) | (1 << INTF1);


    // Config intreupere pin change pe D4 (pt BTN3)
    PCICR |= (1 << PCIE2);
    // Permite intrerupere pe PCINT20
    PCMSK2 |= (1 << PCINT20); 
    // Sterge flag-urile anterioare
    PCIFR |= (1 << PCIF2);


    // Activeaza intreruperile
    sei();

    // It's better to double-check
    init_sender_pins();


    init_tft_lcd();
    draw_straight_through_wiring();
}



void force_stop_handler()
{
    i2c_lcd.clear();
    i2c_lcd.setCursor(0, 0);
    i2c_lcd.print("Force stop!");
    init_sender_pins();
    delay(2000);
    write_full_cable_mode_on_i2c_lcd();
}

void fetch_receiver_socket()
{
    PORTC &= ~(1 << PC1);  // LOW pe pin D15 (register parallel load)
    delayMicroseconds(5);
    PORTC |= (1 << PC1);  // HIGH pe pin D15 (register parallel load)

    // 2. Citește fiecare bit
    for (int i = 0; i < 8; i++) {
        // Shift register-ul transmite serial valorile,
        // incepand cu bitul D7 -> D6 -> ... -> D0 prin pinul QH
        // Se foloseste ordinea MSB -> trebuie inversata din cod
        pinsReceiverSocket[7 - i] = PINC & (1 << PC0);   // read pin D14 (register serial out)

        // Pulseaza ceasul
        PORTC |= (1 << PC2);  // HIGH pe pin D16 (register clock)
        delayMicroseconds(5);
        PORTC &= ~(1 << PC2);  // LOW pe pin D16 (register clock)
        delayMicroseconds(5);
    }
}


bool is_correct_wiring(int pin_index)
{
    fetch_receiver_socket();

    if (cableType == CABLE_TYPE_CROSSOVER) {
        if (pin_index == 0) return pinsReceiverSocket[2];
        else if (pin_index == 1) return pinsReceiverSocket[5];
        else if (pin_index == 2) return pinsReceiverSocket[0];
        else if (pin_index == 3) return pinsReceiverSocket[2];
        else if (pin_index == 4) return pinsReceiverSocket[3];
        else if (pin_index == 5) return pinsReceiverSocket[1];
        else if (pin_index == 6) return pinsReceiverSocket[6];
        else if (pin_index == 7) return pinsReceiverSocket[7];
    }

    if (cableType == CABLE_TYPE_STRAIGHT_THROUGH) {
        return pinsReceiverSocket[pin_index];
    }


    if (cableType == CABLE_TYPE_ROLLOVER) {
        return pinsReceiverSocket[7 - pin_index];
    }


    // unknown cableType
    return false;
}


void test_individual_rj45_pins()
{
    i2c_lcd.setCursor(0, 1);
    i2c_lcd.print("SND ");   // writes 4 chars
    i2c_lcd.setCursor(5, 1);
    i2c_lcd.print("->RCV "); // writes 6 chars



    for (int i = 0; i < 8; i++) {
        pinsSenderSocket[i] = true;
        write_to_sender_socket();
        if (pressedBTN2) {
            force_stop_handler();
            return;
        }


        // Scrie indicele pinului pt SENDER
        i2c_lcd.setCursor(4, 1);
        i2c_lcd.print(i + 1);        // writes 1 digit
        i2c_lcd.setCursor(13, 1);
        i2c_lcd.print("   ");

        // Scrie indiciele pinului pe care RECEIVER ar trb in mod normal sa primeasca semnal
        i2c_lcd.setCursor(11, 1);
        if (cableType == CABLE_TYPE_CROSSOVER) {
            // writes 1 digit
            if (i == 0) i2c_lcd.print(3);
            else if (i == 1) i2c_lcd.print(6);
            else if (i == 2) i2c_lcd.print(1);
            else if (i == 3) i2c_lcd.print(4);
            else if (i == 4) i2c_lcd.print(5);
            else if (i == 5) i2c_lcd.print(2);
            else if (i == 6) i2c_lcd.print(7);
            else if (i == 7) i2c_lcd.print(8);
        } else if (cableType == CABLE_TYPE_STRAIGHT_THROUGH) {
            i2c_lcd.print(i + 1);        // writes 1 digit
        } else if (cableType == CABLE_TYPE_ROLLOVER) {
            i2c_lcd.print(8 - i);       // writes 1 digit
        }



        // 1s pause betweem testing another RJ45 pin
        for (int j = 0; j < 10; j++) {
            if (pressedBTN2) {
                force_stop_handler();
                return;
            }
            delay(100);
        }

        pinsSenderSocket[i] = false;
        write_to_sender_socket();
        if (pressedBTN2) {
            force_stop_handler();
            return;
        }
        
        delay(20);  // un mic delay pt a astepta semnalul pe cablu
        if (is_correct_wiring(i)) {
            i2c_lcd.setCursor(13, 1);
            i2c_lcd.print(" OK");
            beep_okay();
            delay(340);
        } else {
            i2c_lcd.setCursor(13, 1);
            i2c_lcd.print("NOK");
            beep_not_okay();
        }
  
        if (pressedBTN2) {
            force_stop_handler();
            return;
        }

        delay(500);
        if (pressedBTN2) {
            force_stop_handler();
            return;
        }

    }


    init_sender_pins();
    write_cable_type_on_first_line_of_i2c_lcd();
    i2c_lcd.setCursor(0, 1);
    i2c_lcd.print("Done            ");
    delay(2000);
    write_full_cable_mode_on_i2c_lcd();

}



void loop() {
    if (pressedBTN1 && !pressedBTN2 && !pressedBTN3) {
        // Butonul albastru a fost apasat: schimba tipul de cablare

        imageTypeOnDisplay = (imageTypeOnDisplay + 1) % 6;
        cableType = (cableType + 1) % 3;
        write_full_cable_mode_on_i2c_lcd();


        if (imageTypeOnDisplay == 0) draw_straight_through_wiring();
        else if (imageTypeOnDisplay == 1) draw_crossover_wiring();
        else if (imageTypeOnDisplay == 2) draw_rollover_wiring();
        else if (imageTypeOnDisplay == 3)  draw_straight_through_rj45_socket();
        else if (imageTypeOnDisplay == 4)  draw_crossover_rj45_socket();
        else if (imageTypeOnDisplay == 5)  draw_rollover_rj45_socket();
    } else if (pressedBTN3 && !pressedBTN1 && !pressedBTN2) {
        // Butonul alb a fost apast: porneste tester-ul
        isRunningTest = true;
        i2c_lcd.clear();
        write_cable_type_on_first_line_of_i2c_lcd();

        i2c_lcd.setCursor(0, 1);
        i2c_lcd.print("Testing pin: ");

        test_individual_rj45_pins();
        init_sender_pins();
        isRunningTest = false;
    }

    pressedBTN1 = false;
    pressedBTN2 = false;
    pressedBTN3 = false;
    delay(200);
}

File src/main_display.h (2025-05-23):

#include <Adafruit_GFX.h>
#include <Adafruit_ST7735.h>


// Rezolutie: 160x128

// Pini pentru display-ul 160x128
#define TFT_CS    10
#define TFT_DC    A3
#define TFT_RST   -1


Adafruit_ST7735 tft_lcd = Adafruit_ST7735(TFT_CS, TFT_DC, TFT_RST);

#define COLOR_BROWN   tft_lcd.color565(112, 55, 14)



void init_tft_lcd()
{
    // Init SPI 128x160 display
    tft_lcd.initR(INITR_BLACKTAB);      // Initialize display
    tft_lcd.setRotation(1);             // Optional: change to 0-3 based on setup
    tft_lcd.fillScreen(ST77XX_BLACK);   // Clear screen
}



/*
* In stanga - prima varianta de cablare:
*           Sender     <->   Receiver
* Pin 1   white-orange <-> white-orange
* Pin 2   orange       <-> orange
* Pin 3   white-green  <-> white-green
* Pin 4   blue         <-> blue
* Pin 5   white-blue   <-> white-blue
* Pin 6   green        <-> green
* Pin 7   white-brown  <-> white-brown
* Pin 8   brown        <-> brown
*
*
* In dreapta - a doua varianta de cablare:
*           Sender     <->   Receiver
* Pin 1   white-green  <-> white-green
* Pin 2   green        <-> green
* Pin 3   white-orange <-> white-orange
* Pin 4   blue         <-> blue
* Pin 5   white-blue   <-> white-blue
* Pin 6   orange       <-> orange
* Pin 7   white-brown  <-> white-brown
* Pin 8   brown        <-> brown
*

* (x, y) -> upper left corner
* tft_lcd.fillRect(x, y, width, height, <color>);
* 
*/
void draw_straight_through_wiring()
{
    init_tft_lcd();

    const int BOX_WIDTH = 12;
    const int BOX_HEIGHT = 10;

    const int WIRE_WIDTH = 17;
    const int WIRE_HEIGHT = 2;

    const int Y_OFFSET_BTWN_BOXES = 5;
    const int WIDTH_SEP_LINE = 4;



    const int Y_OFFSET = (tft_lcd.height() - 8 * BOX_HEIGHT - 7 * Y_OFFSET_BTWN_BOXES) / 2;

    
    // Prima varianta de cablare:
    const int X_OFFSET_1 = (tft_lcd.width() / 2 - WIDTH_SEP_LINE / 2 - 4 * BOX_WIDTH - WIRE_WIDTH) / 2;

    // Pin 1   white-orange <-> white-orange
    tft_lcd.fillRect(X_OFFSET_1                             , Y_OFFSET, BOX_WIDTH, BOX_HEIGHT, ST77XX_WHITE);
    tft_lcd.fillRect(X_OFFSET_1 + BOX_WIDTH                 , Y_OFFSET, BOX_WIDTH, BOX_HEIGHT, ST77XX_ORANGE);
    tft_lcd.fillRect(X_OFFSET_1 + 2 * BOX_WIDTH, Y_OFFSET + 0 * (Y_OFFSET_BTWN_BOXES + BOX_HEIGHT) + (BOX_HEIGHT - WIRE_HEIGHT) / 2, WIRE_WIDTH, WIRE_HEIGHT, ST77XX_YELLOW);
    tft_lcd.fillRect(X_OFFSET_1 + 2 * BOX_WIDTH + WIRE_WIDTH, Y_OFFSET, BOX_WIDTH, BOX_HEIGHT, ST77XX_WHITE);
    tft_lcd.fillRect(X_OFFSET_1 + 3 * BOX_WIDTH + WIRE_WIDTH, Y_OFFSET, BOX_WIDTH, BOX_HEIGHT, ST77XX_ORANGE);

    // Pin 2   orange       <-> orange
    tft_lcd.fillRect(X_OFFSET_1                             , Y_OFFSET + BOX_HEIGHT + Y_OFFSET_BTWN_BOXES, BOX_WIDTH * 2, BOX_HEIGHT, ST77XX_ORANGE);
    tft_lcd.fillRect(X_OFFSET_1 + 2 * BOX_WIDTH, Y_OFFSET + (Y_OFFSET_BTWN_BOXES + BOX_HEIGHT) + (BOX_HEIGHT - WIRE_HEIGHT) / 2, WIRE_WIDTH, WIRE_HEIGHT, ST77XX_YELLOW);
    tft_lcd.fillRect(X_OFFSET_1 + 2 * BOX_WIDTH + WIRE_WIDTH, Y_OFFSET + BOX_HEIGHT + Y_OFFSET_BTWN_BOXES, BOX_WIDTH * 2, BOX_HEIGHT, ST77XX_ORANGE);

    // Pin 3   white-green <-> white-green
    tft_lcd.fillRect(X_OFFSET_1                             , Y_OFFSET + 2 * (BOX_HEIGHT + Y_OFFSET_BTWN_BOXES), BOX_WIDTH, BOX_HEIGHT, ST77XX_WHITE);
    tft_lcd.fillRect(X_OFFSET_1 + BOX_WIDTH                 , Y_OFFSET + 2 * (BOX_HEIGHT + Y_OFFSET_BTWN_BOXES), BOX_WIDTH, BOX_HEIGHT, ST77XX_GREEN);
    tft_lcd.fillRect(X_OFFSET_1 + 2 * BOX_WIDTH, Y_OFFSET + 2 * (Y_OFFSET_BTWN_BOXES + BOX_HEIGHT) + (BOX_HEIGHT - WIRE_HEIGHT) / 2, WIRE_WIDTH, WIRE_HEIGHT, ST77XX_YELLOW);
    tft_lcd.fillRect(X_OFFSET_1 + 2 * BOX_WIDTH + WIRE_WIDTH, Y_OFFSET + 2 * (BOX_HEIGHT + Y_OFFSET_BTWN_BOXES), BOX_WIDTH, BOX_HEIGHT, ST77XX_WHITE);
    tft_lcd.fillRect(X_OFFSET_1 + 3 * BOX_WIDTH + WIRE_WIDTH, Y_OFFSET + 2 * (BOX_HEIGHT + Y_OFFSET_BTWN_BOXES), BOX_WIDTH, BOX_HEIGHT, ST77XX_GREEN);

    // Pin 4   blue         <-> blue
    tft_lcd.fillRect(X_OFFSET_1                             , Y_OFFSET + 3 * (BOX_HEIGHT + Y_OFFSET_BTWN_BOXES), BOX_WIDTH * 2, BOX_HEIGHT, ST77XX_BLUE);
    tft_lcd.fillRect(X_OFFSET_1 + 2 * BOX_WIDTH, Y_OFFSET + 3 * (Y_OFFSET_BTWN_BOXES + BOX_HEIGHT) + (BOX_HEIGHT - WIRE_HEIGHT) / 2, WIRE_WIDTH, WIRE_HEIGHT, ST77XX_YELLOW);
    tft_lcd.fillRect(X_OFFSET_1 + 2 * BOX_WIDTH + WIRE_WIDTH, Y_OFFSET + 3 * (BOX_HEIGHT + Y_OFFSET_BTWN_BOXES), BOX_WIDTH * 2, BOX_HEIGHT, ST77XX_BLUE);

    // Pin 5   white-blue   <-> white-blue
    tft_lcd.fillRect(X_OFFSET_1                             , Y_OFFSET + 4 * (BOX_HEIGHT + Y_OFFSET_BTWN_BOXES), BOX_WIDTH, BOX_HEIGHT, ST77XX_WHITE);
    tft_lcd.fillRect(X_OFFSET_1 + BOX_WIDTH                 , Y_OFFSET + 4 * (BOX_HEIGHT + Y_OFFSET_BTWN_BOXES), BOX_WIDTH, BOX_HEIGHT, ST77XX_BLUE);
    tft_lcd.fillRect(X_OFFSET_1 + 2 * BOX_WIDTH, Y_OFFSET + 4 * (Y_OFFSET_BTWN_BOXES + BOX_HEIGHT) + (BOX_HEIGHT - WIRE_HEIGHT) / 2, WIRE_WIDTH, WIRE_HEIGHT, ST77XX_YELLOW);
    tft_lcd.fillRect(X_OFFSET_1 + 2 * BOX_WIDTH + WIRE_WIDTH, Y_OFFSET + 4 * (BOX_HEIGHT + Y_OFFSET_BTWN_BOXES), BOX_WIDTH, BOX_HEIGHT, ST77XX_WHITE);
    tft_lcd.fillRect(X_OFFSET_1 + 3 * BOX_WIDTH + WIRE_WIDTH, Y_OFFSET + 4 * (BOX_HEIGHT + Y_OFFSET_BTWN_BOXES), BOX_WIDTH, BOX_HEIGHT, ST77XX_BLUE);

    // Pin 6   green        <-> green
    tft_lcd.fillRect(X_OFFSET_1                             , Y_OFFSET + 5 * (BOX_HEIGHT + Y_OFFSET_BTWN_BOXES), BOX_WIDTH * 2, BOX_HEIGHT, ST77XX_GREEN);
    tft_lcd.fillRect(X_OFFSET_1 + 2 * BOX_WIDTH, Y_OFFSET + 5 * (Y_OFFSET_BTWN_BOXES + BOX_HEIGHT) + (BOX_HEIGHT - WIRE_HEIGHT) / 2, WIRE_WIDTH, WIRE_HEIGHT, ST77XX_YELLOW);
    tft_lcd.fillRect(X_OFFSET_1 + 2 * BOX_WIDTH + WIRE_WIDTH, Y_OFFSET + 5 * (BOX_HEIGHT + Y_OFFSET_BTWN_BOXES), BOX_WIDTH * 2, BOX_HEIGHT, ST77XX_GREEN);

    // Pin 7   white-brown  <-> white-brown
    tft_lcd.fillRect(X_OFFSET_1                             , Y_OFFSET + 6 * (BOX_HEIGHT + Y_OFFSET_BTWN_BOXES), BOX_WIDTH, BOX_HEIGHT, ST77XX_WHITE);
    tft_lcd.fillRect(X_OFFSET_1 + BOX_WIDTH                 , Y_OFFSET + 6 * (BOX_HEIGHT + Y_OFFSET_BTWN_BOXES), BOX_WIDTH, BOX_HEIGHT, COLOR_BROWN);
    tft_lcd.fillRect(X_OFFSET_1 + 2 * BOX_WIDTH, Y_OFFSET + 6 * (Y_OFFSET_BTWN_BOXES + BOX_HEIGHT) + (BOX_HEIGHT - WIRE_HEIGHT) / 2, WIRE_WIDTH, WIRE_HEIGHT, ST77XX_YELLOW);
    tft_lcd.fillRect(X_OFFSET_1 + 2 * BOX_WIDTH + WIRE_WIDTH, Y_OFFSET + 6 * (BOX_HEIGHT + Y_OFFSET_BTWN_BOXES), BOX_WIDTH, BOX_HEIGHT, ST77XX_WHITE);
    tft_lcd.fillRect(X_OFFSET_1 + 3 * BOX_WIDTH + WIRE_WIDTH, Y_OFFSET + 6 * (BOX_HEIGHT + Y_OFFSET_BTWN_BOXES), BOX_WIDTH, BOX_HEIGHT, COLOR_BROWN);
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

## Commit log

2025-05-06 Changing env to Arduino NANO
2025-05-06 Interrupt attached on BTN1
2025-05-07 feedback on LCD for pressing buttons
2025-05-07 Shift register on sender socket&LEDs
2025-05-07 Trying to solve edge case for remaining LED after force stop
2025-05-08 Hardware: explained LEDs and resistors I used
2025-05-11 Added KiCad Schemtatics
    [rj45.kicad_pcb, rj45.kicad_sch]
2025-05-11 Schema electrica
    [rj45.kicad_sch]
2025-05-11 HW progress on stages
2025-05-12 Schematics using official 74HC595 shift register
    [SN74HC595N.step]
2025-05-14 Buttons with low-pass filters
    [rj45.kicad_sch]
2025-05-16 Added microSD module on SPI
2025-05-19 Organizing on dirs && I2C LCD prints pin idx to test
    [SN74HC595N.step, rj45.kicad_pcb, rj45.kicad_sch]
2025-05-19 Logic to check RJ45 wiring
2025-05-19 Cannot switch cable mode while testing
2025-05-19 Schematics inlcude SPI display
    [rj45.kicad_sch]
2025-05-21 Connecting SPI display
2025-05-23 Draw straight-through on SPI display
2025-05-23 Drawing 'yellow wires' for straight_through on main display
2025-05-23 Drawing crossover/rolover wiring on the TFT LCD
2025-05-24 Am renuntat la cardul SD
    [rj45.kicad_sch]
2025-05-24 README: detailed pin configs
    [rj45.kicad_sch]
2025-05-24 Am adaugat link-uri la listele de componente
2025-05-24 Updated ocw doc with pin configs
2025-05-29 Drawing wiring of rj45 socket on SPI display
2025-05-30 Corrected comments HIGH/LOW in write_to_sender_socket
    [main.cpp]
